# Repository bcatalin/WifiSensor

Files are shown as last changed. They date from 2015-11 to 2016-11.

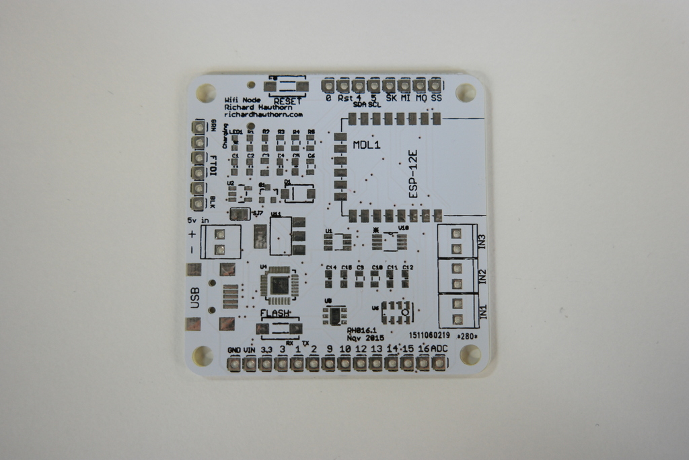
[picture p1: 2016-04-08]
images/image2.jpg

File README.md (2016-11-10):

### Description

A wifi sensor, designed to collect and report various sensor readings over wifi.

### Sensors

- HTU21D (Temperature + Humidity)
- MCP9808 (Temperature)
- MPL3115A2 (Pressure)
- TSL2561 (Light)
- 3x Inputs/Outputs

### Other Features

- ESP8266
- 3.3V operation
- Mini USB power connector
- Li-po charger
- Battery charging LED
- Automatic battery/USB power switching
- Solar panel input
- FTDI programming port
- Choice of 2 serial uart converters, CH340G or CP2102

### License

This work is licensed under a Creative Commons Attribution-ShareAlike 4.0 International License.

<br />
Designed by <a xmlns:cc="http://creativecommons.org/ns#" href="http://www.richardhawthorn.com" property="cc:attributionName" rel="cc:attributionURL" target="_blank">Richard Hawthorn</a><br />
<a rel="license" href="http://creativecommons.org/licenses/by-sa/4.0/" target="_blank">View License</a>

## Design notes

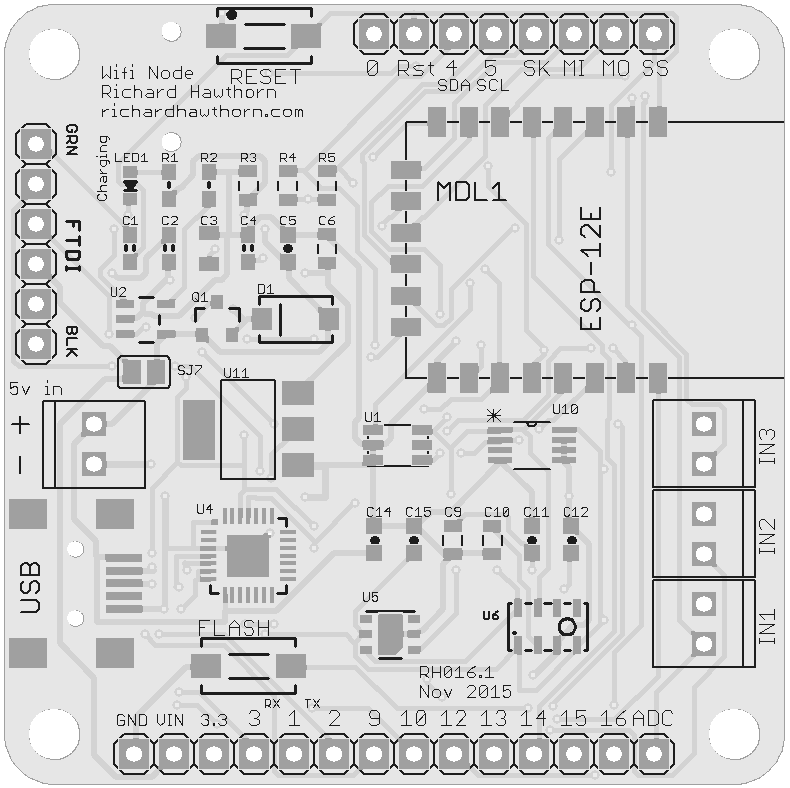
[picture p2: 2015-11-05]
images/pcb_front.png

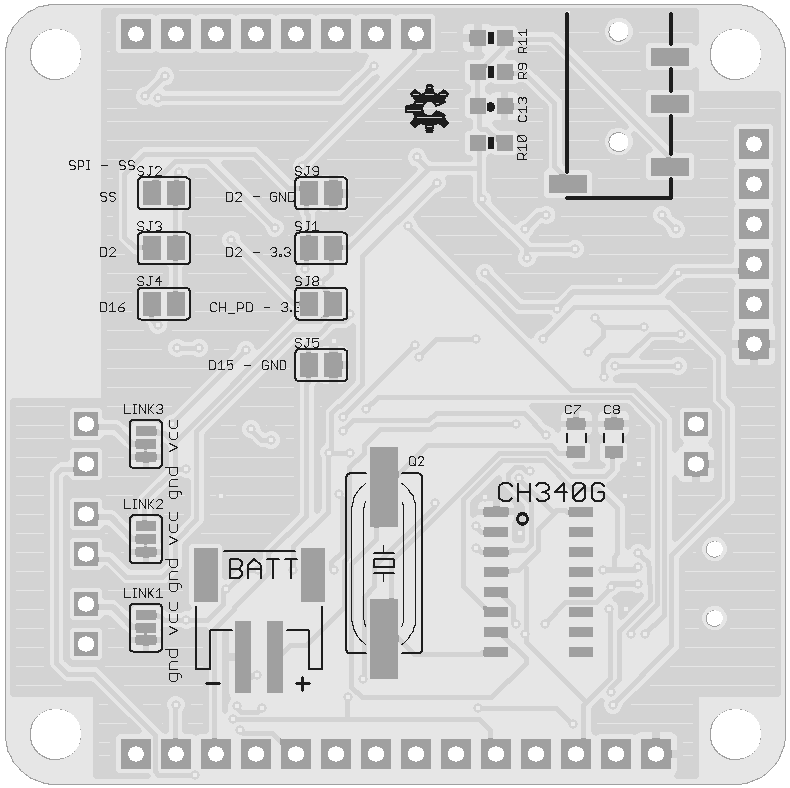
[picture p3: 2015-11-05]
images/pcb_back.png

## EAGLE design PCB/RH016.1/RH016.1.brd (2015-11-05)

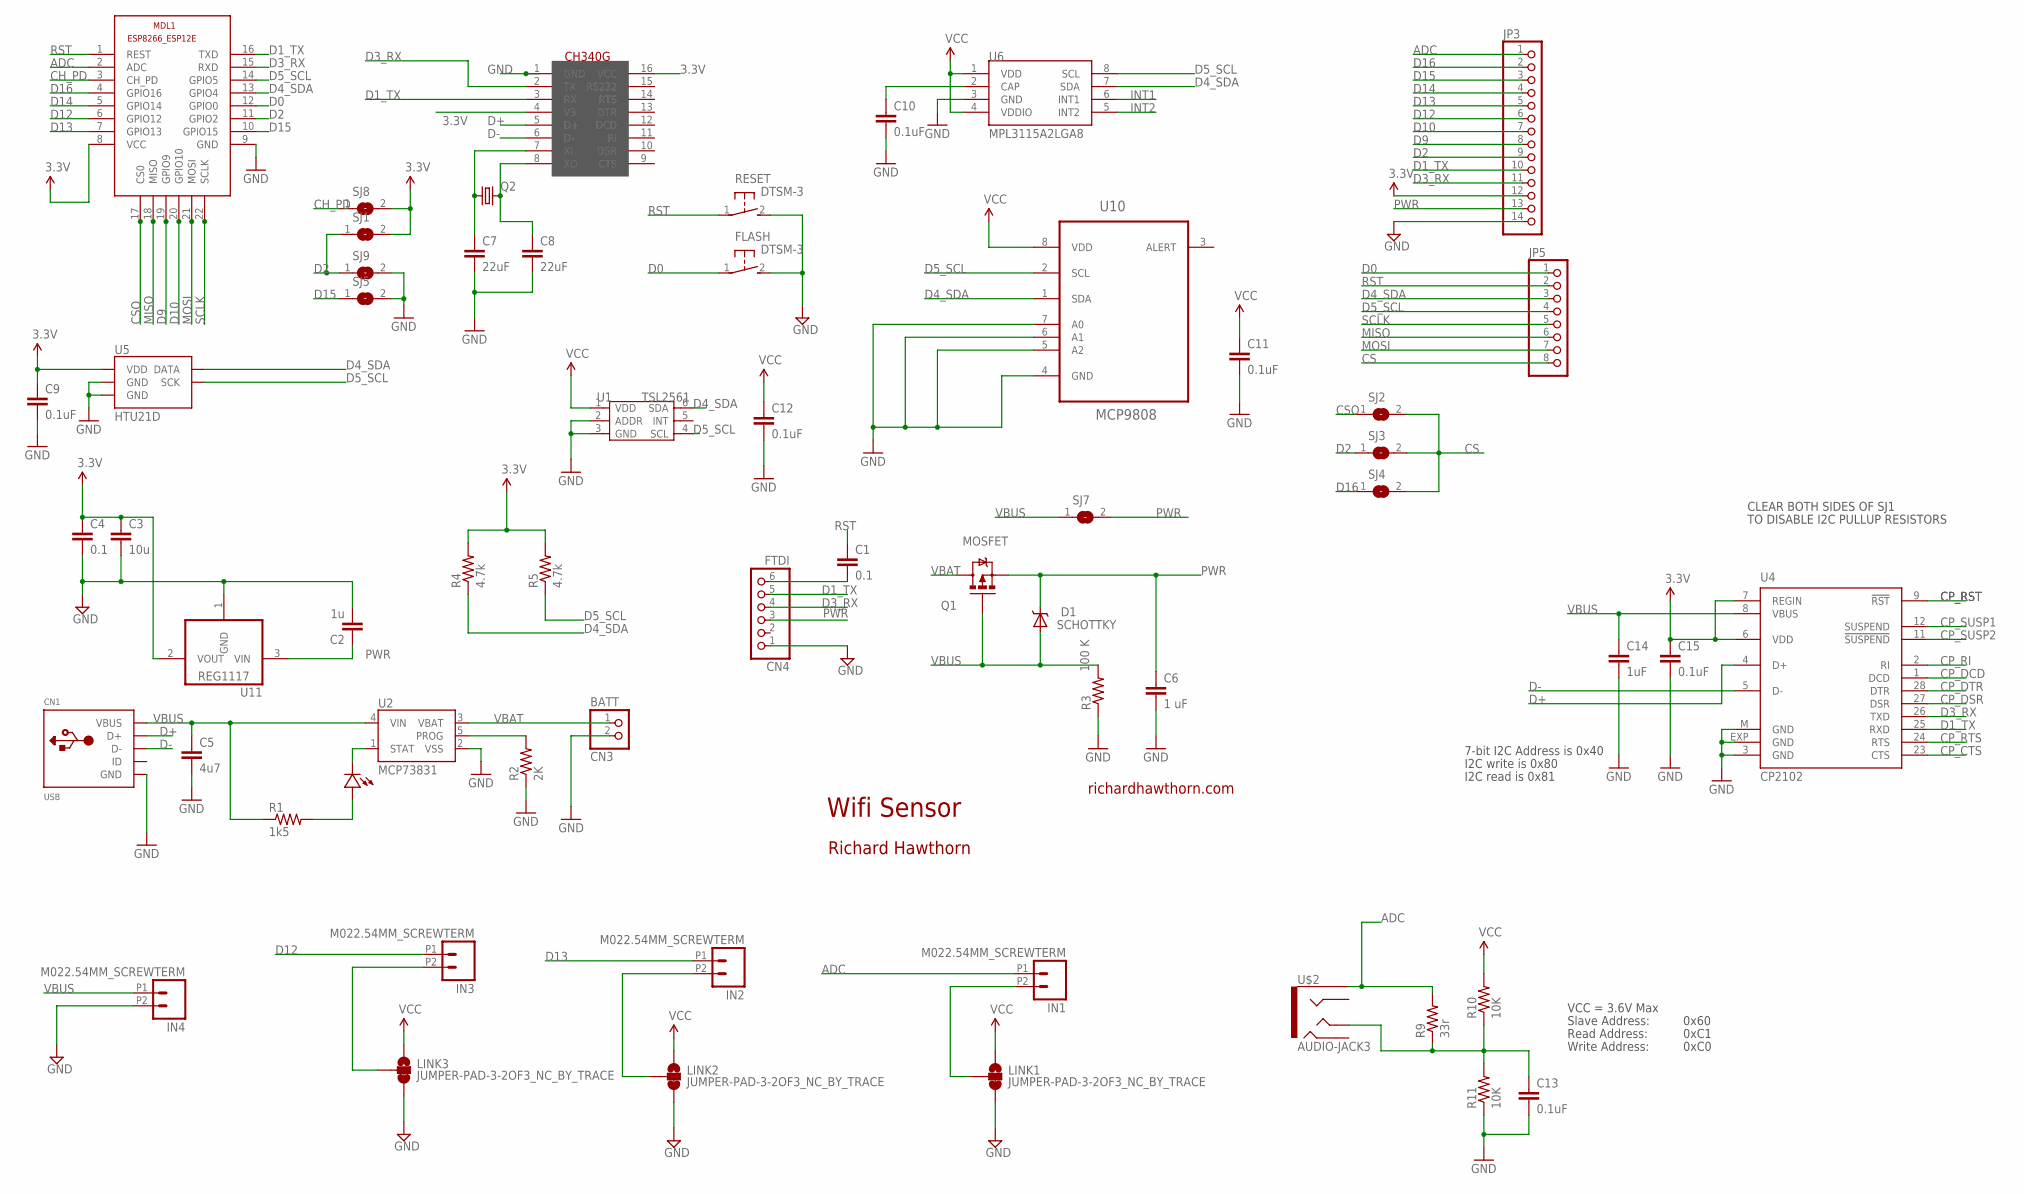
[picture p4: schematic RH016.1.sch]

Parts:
C1, C4: 0.1; 0603-CAP
C2: 1u; 0603-CAP
C3: 10u; 0805-CAP
C5: 4u7; 0603-CAP
C6: 1 uF; 0805
C7, C8: 22uF; 0805
C9, C10: 0.1uF; 0805
C11, C12, C13, C15: 0.1uF; 0603-CAP
C14: 1uF; 0603-CAP
CN1: USB; USB-MINIB
CN3: BATT; JST-PH-2-SMT-RA
CN4: FTDI; 1X06
D1: SCHOTTKY; SMA-DIODE
FLASH: DTSM-3
IN1, IN2, IN3, IN4: M022.54MM_SCREWTERM; 1X02_2.54_SCREWTERM
JP3: PINHD-1X14; 1X14
JP5: PINHD-1X8; 1X08
LED1: LED0603; 0603-LED
LINK1, LINK2, LINK3: JUMPER-PAD-3-2OF3_NC_BY_TRACE; PAD-JUMPER-3-2OF3_NC_BY_TRACE_YES_SILK_FULL_BOX
MDL1: ESP8266-12EESP8266-ESP12E; ESP8266-ESP12E
Q1: MOSFET; SOT23-3
Q2: CRYSTALSM49; SM49
R1: 1k5; 0603-RES
R2: 2K; 0603-RES
R3: 100 K; 0805
R4, R5: 4.7k; 0805
R9: 33r; 0603-RES
R10, R11: 10K; 0603-RES
RESET: DTSM-3
SJ1, SJ2, SJ3, SJ4, SJ5, SJ7, SJ8, SJ9: SJ
U1: TSL2561; TMB-6
U2: MCP73831; SOT23-5
U4: CP2102; MLP28
U5: HTU21D
U6: MPL3115A2LGA8; LGA8
U10: MCP9808; SOP65P490X110-8N
U11: REG1117; SOT223
U$2: AUDIO-JACK3; AUDIO-JACK-TRRS-SMD
U$4: CH340G; SOIC16

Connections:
3.3V: C3.1, C4.1, C9.1, C11.1, C12.1, C15.1, JP3.12, LINK1.1, LINK2.1, LINK3.1, MDL1.8 (VCC), R4.2, R5.2, R10.2, SJ1.2, SJ8.2, U1.1 (VDD), U4.6 (VDD), U4.7 (REGIN), U5.VDD, U6.1 (VDD), U6.4 (VDDIO), U10.8 (VDD), U11.2 (VOUT), U$4.4 (V3), U$4.16 (VCC)
ADC: IN1.P1 (1), JP3.1, MDL1.2 (ADC), R9.2, U$2.EARTH
CH_PD: MDL1.3 (CH_PD), SJ8.1
CP_CTS: U4.23 (CTS)
CP_DCD: U4.1 (DCD)
CP_DSR: U4.27 (DSR)
CP_DTR: U4.28 (DTR)
CP_RI: U4.2 (RI)
CP_RST: U4.9 (!RST)
CP_RTS: U4.24 (RTS)
CP_SUSP1: U4.12 (SUSPEND)
CP_SUSP2: U4.11 (!SUSPEND)
CS: JP5.8, SJ2.2, SJ3.2, SJ4.2
CSO: MDL1.17 (CS0), SJ2.1
D0: FLASH.1, JP5.1, MDL1.12 (GPIO0)
D1_TX: CN4.5, JP3.10, MDL1.16 (TXD), U4.25 (RXD), U$4.3 (RX)
D2: JP3.9, MDL1.11 (GPIO2), SJ1.1, SJ3.1, SJ9.1
D3_RX: CN4.4, JP3.11, MDL1.15 (RXD), U4.26 (TXD), U$4.2 (TX)
D4_SDA: JP5.3, MDL1.13 (GPIO4), R4.1, U1.6 (SDA), U5.DATA, U6.7 (SDA), U10.1 (SDA)
D5_SCL: JP5.4, MDL1.14 (GPIO5), R5.1, U1.4 (SCL), U5.SCK, U6.8 (SCL), U10.2 (SCL)
D9: JP3.8, MDL1.19 (GPIO9)
D10: JP3.7, MDL1.20 (GPIO10)
D12: IN3.P1 (1), JP3.6, MDL1.6 (GPIO12)
D13: IN2.P1 (1), JP3.5, MDL1.7 (GPIO13)
D14: JP3.4, MDL1.5 (GPIO14)
D15: JP3.3, MDL1.10 (GPIO15), SJ5.1
D16: JP3.2, MDL1.4 (GPIO16), SJ4.1
D+: CN1.D+, U4.4 (D+), U$4.5 (D+)
D-: CN1.D-, U4.5 (D-), U$4.6 (D-)
GND: C2.2, C3.2, C4.2, C5.2, C6.2, C7.2, C8.2, C9.2, C10.2, C11.2, C12.2, C13.2, C14.2, C15.2, CN1.GND, CN3.2 (1), CN4.1, FLASH.2, IN4.P2 (2), JP3.14, LINK1.3, LINK2.3, LINK3.3, MDL1.9 (GND), R2.1, R3.1, R11.1, RESET.2, SJ5.2, SJ9.2, U1.2 (ADDR), U1.3 (GND), U2.2 (VSS), U4.3 (GND), U4.EXP (GND), U4.M (GND), U5.7 (GND), U5.GND, U6.3 (GND), U10.4 (GND), U10.5 (A2), U10.6 (A1), U10.7 (A0), U11.1 (GND), U$4.1 (GND)
INT1: U6.6 (INT1)
INT2: U6.5 (INT2)
MISO: JP5.6, MDL1.18 (MISO)
MOSI: JP5.7, MDL1.21 (MOSI)
unnamed: C7.1, Q2.1, U$4.7 (XI)
unnamed: C8.1, Q2.2, U$4.8 (XO)
unnamed: LED1.PLUS, R1.2
unnamed: C10.1, U6.2 (CAP)
unnamed: IN1.P2 (2), LINK1.2
unnamed: C13.1, R9.1, R10.1, R11.2, U$2.TIP
unnamed: IN2.P2 (2), LINK2.2
unnamed: IN3.P2 (2), LINK3.2
unnamed: C1.2, CN4.6
PROG: R2.2, U2.5 (PROG)
PWR: C2.1, C6.1, CN4.3, D1.C, JP3.13, Q1.2 (S), SJ7.2, U11.3 (VIN)
RST: C1.1, JP5.2, MDL1.1 (REST), RESET.1
SCLK: JP5.5, MDL1.22 (SCLK)
STAT: LED1.MINUS, U2.1 (STAT)
VBAT: CN3.1 (2), Q1.3 (D), U2.3 (VBAT)
VBUS: C5.1, C14.1, CN1.VBUS, D1.A, IN4.P1 (1), Q1.1 (G), R1.1, R3.2, SJ7.1, U2.4 (VIN), U4.8 (VBUS)

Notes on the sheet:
Wifi Sensor
richardhawthorn.com
Richard Hawthorn
CLEAR BOTH SIDES OF SJ1
TO DISABLE I2C PULLUP RESISTORS
7-bit I2C Address is 0x40
I2C write is 0x80
I2C read is 0x81
VCC = 3.6V Max
Read Address:
Write Address:
Slave Address:
0x60
0xC1
0xC0

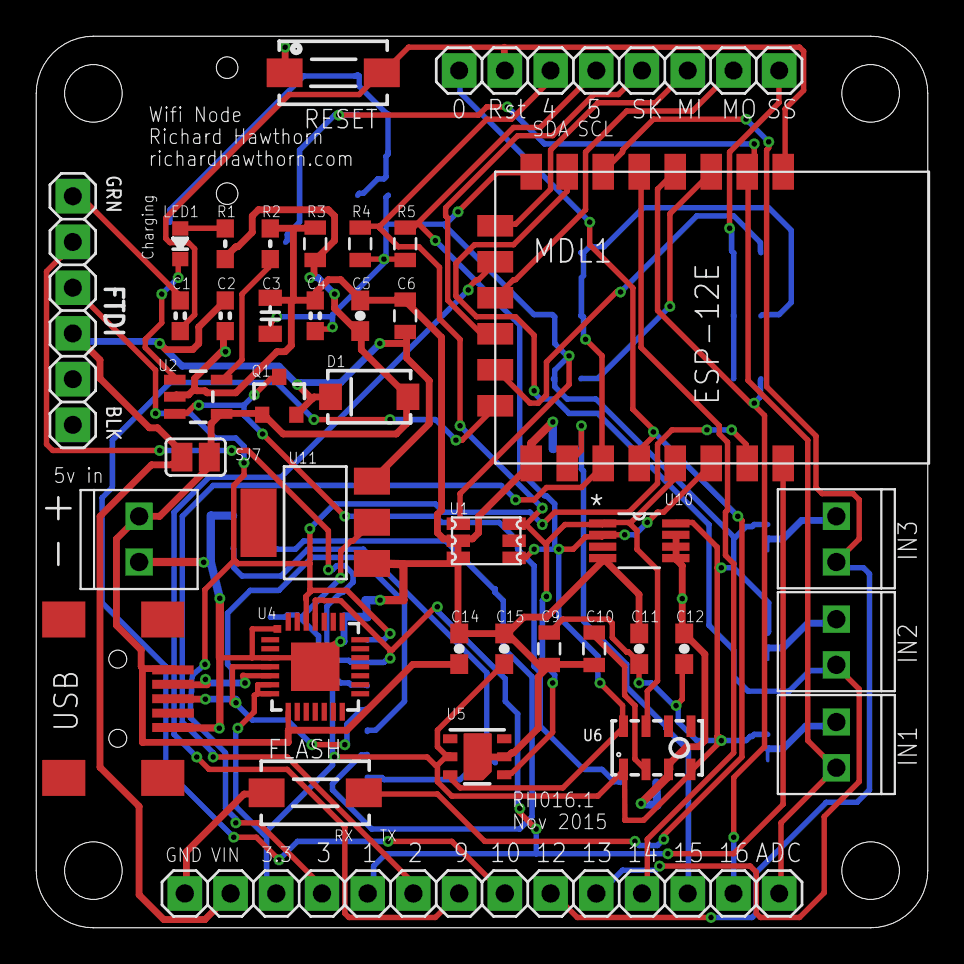
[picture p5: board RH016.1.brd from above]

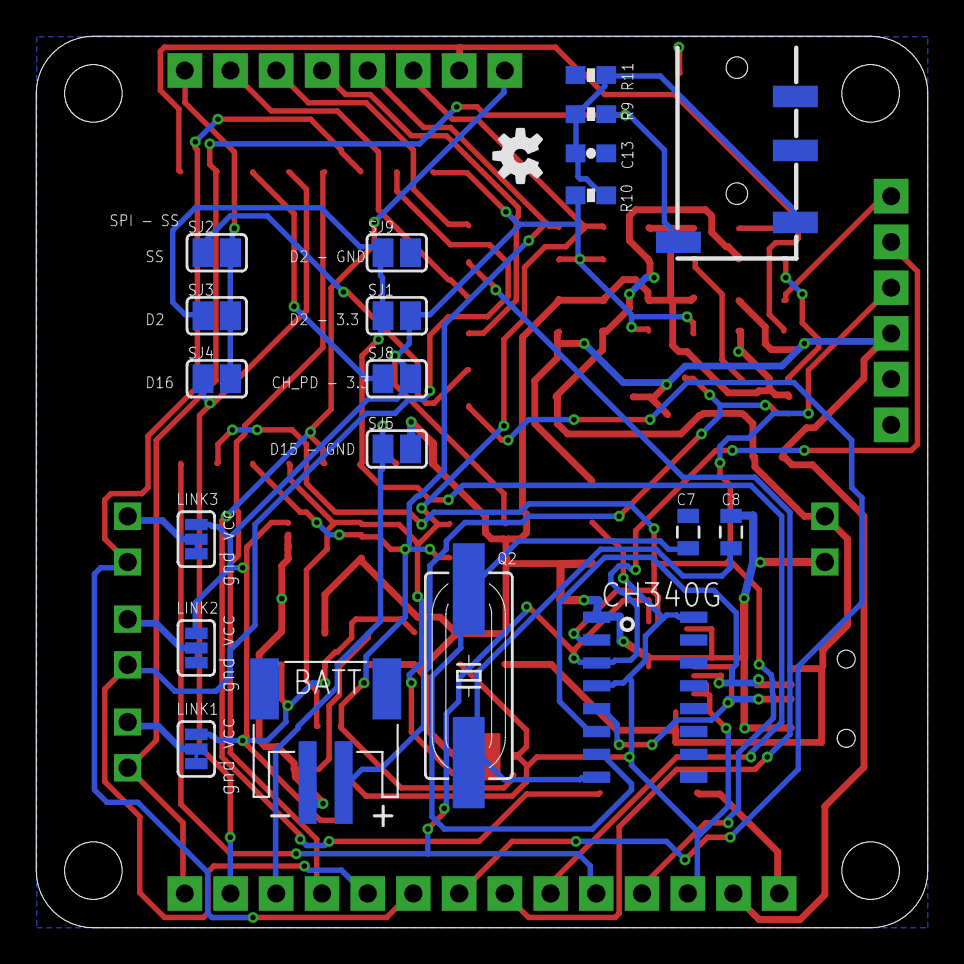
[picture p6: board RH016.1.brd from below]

Board: 2 copper layers, 49.5 x 49.5 mm, 60 parts (21 on the bottom side), 39 nets.

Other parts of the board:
U$3: OSHW-LOGO-S

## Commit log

2015-11-05 adding design files
    [RH016.1.brd, RH016.1.sch]
2015-11-05 front pcb image
2015-11-05 added gerber
2016-04-08 rename folder
    [RH016.1.brd, RH016.1.sch]

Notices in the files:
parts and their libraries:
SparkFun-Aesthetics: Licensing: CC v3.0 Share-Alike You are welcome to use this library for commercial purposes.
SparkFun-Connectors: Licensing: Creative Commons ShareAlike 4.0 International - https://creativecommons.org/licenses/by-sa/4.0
